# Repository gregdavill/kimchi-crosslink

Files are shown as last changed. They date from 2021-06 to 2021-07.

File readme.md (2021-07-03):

# kimχ micro lid Crosslink-nx

This project is an add-on (lid) expansion board for the [kimχ micro i.MX8M Mini SBC](https://labs.groupgets.com/kimchi-micro).

This board is designed as a general purpose plotform for the Lattice Crosslink-nx FPGA, but it's main purpose is to investigate the options for converting the 4-lane MIPI-DSI signals from the Kimchi to a standard HDMI monitor.

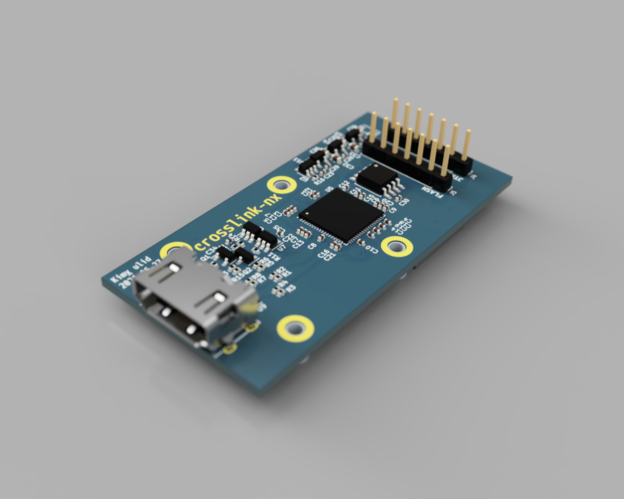
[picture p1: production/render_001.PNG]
Render 001

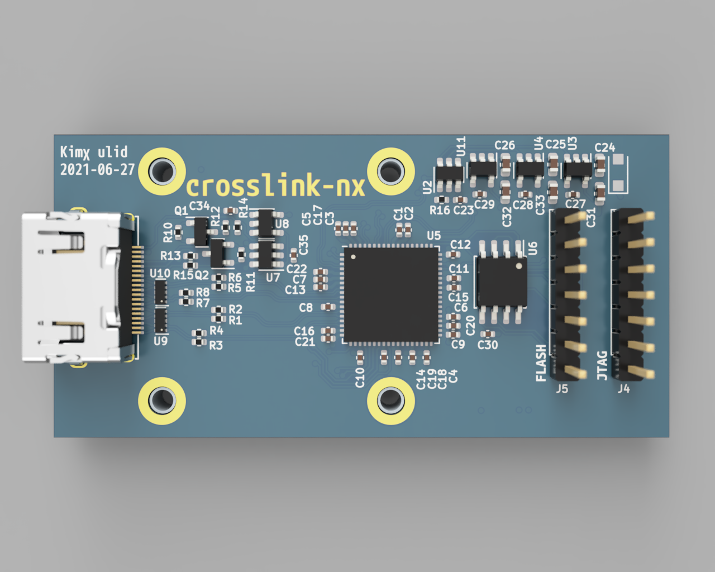
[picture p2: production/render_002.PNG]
Render 002


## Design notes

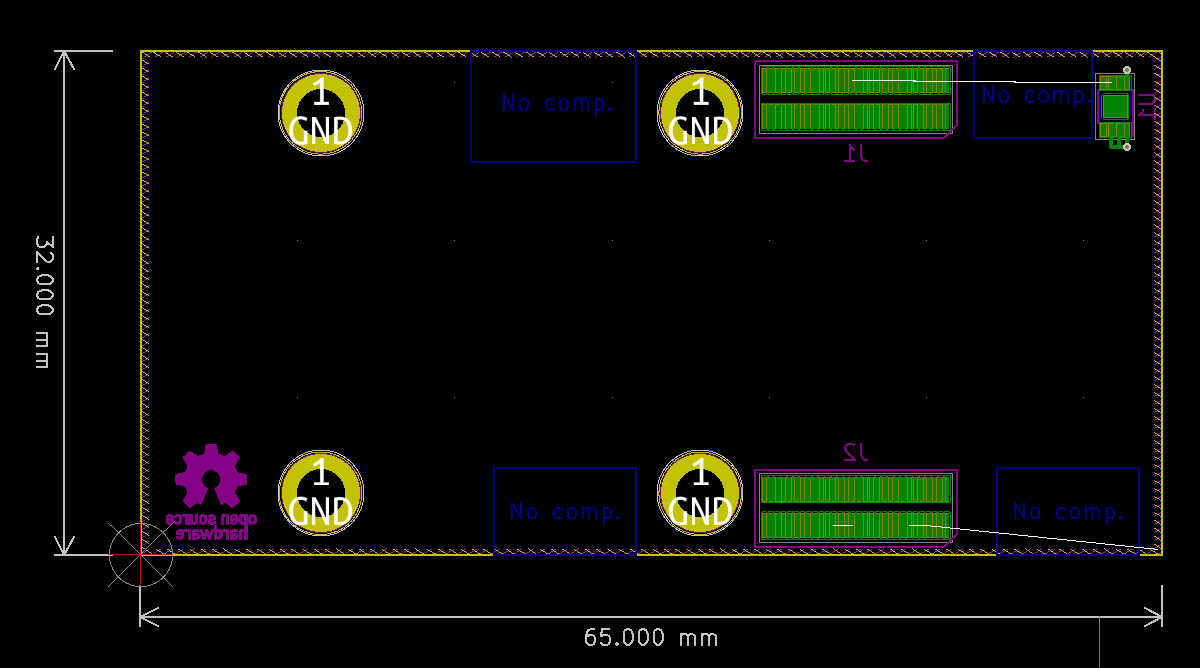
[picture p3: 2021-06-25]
meta/brd.png

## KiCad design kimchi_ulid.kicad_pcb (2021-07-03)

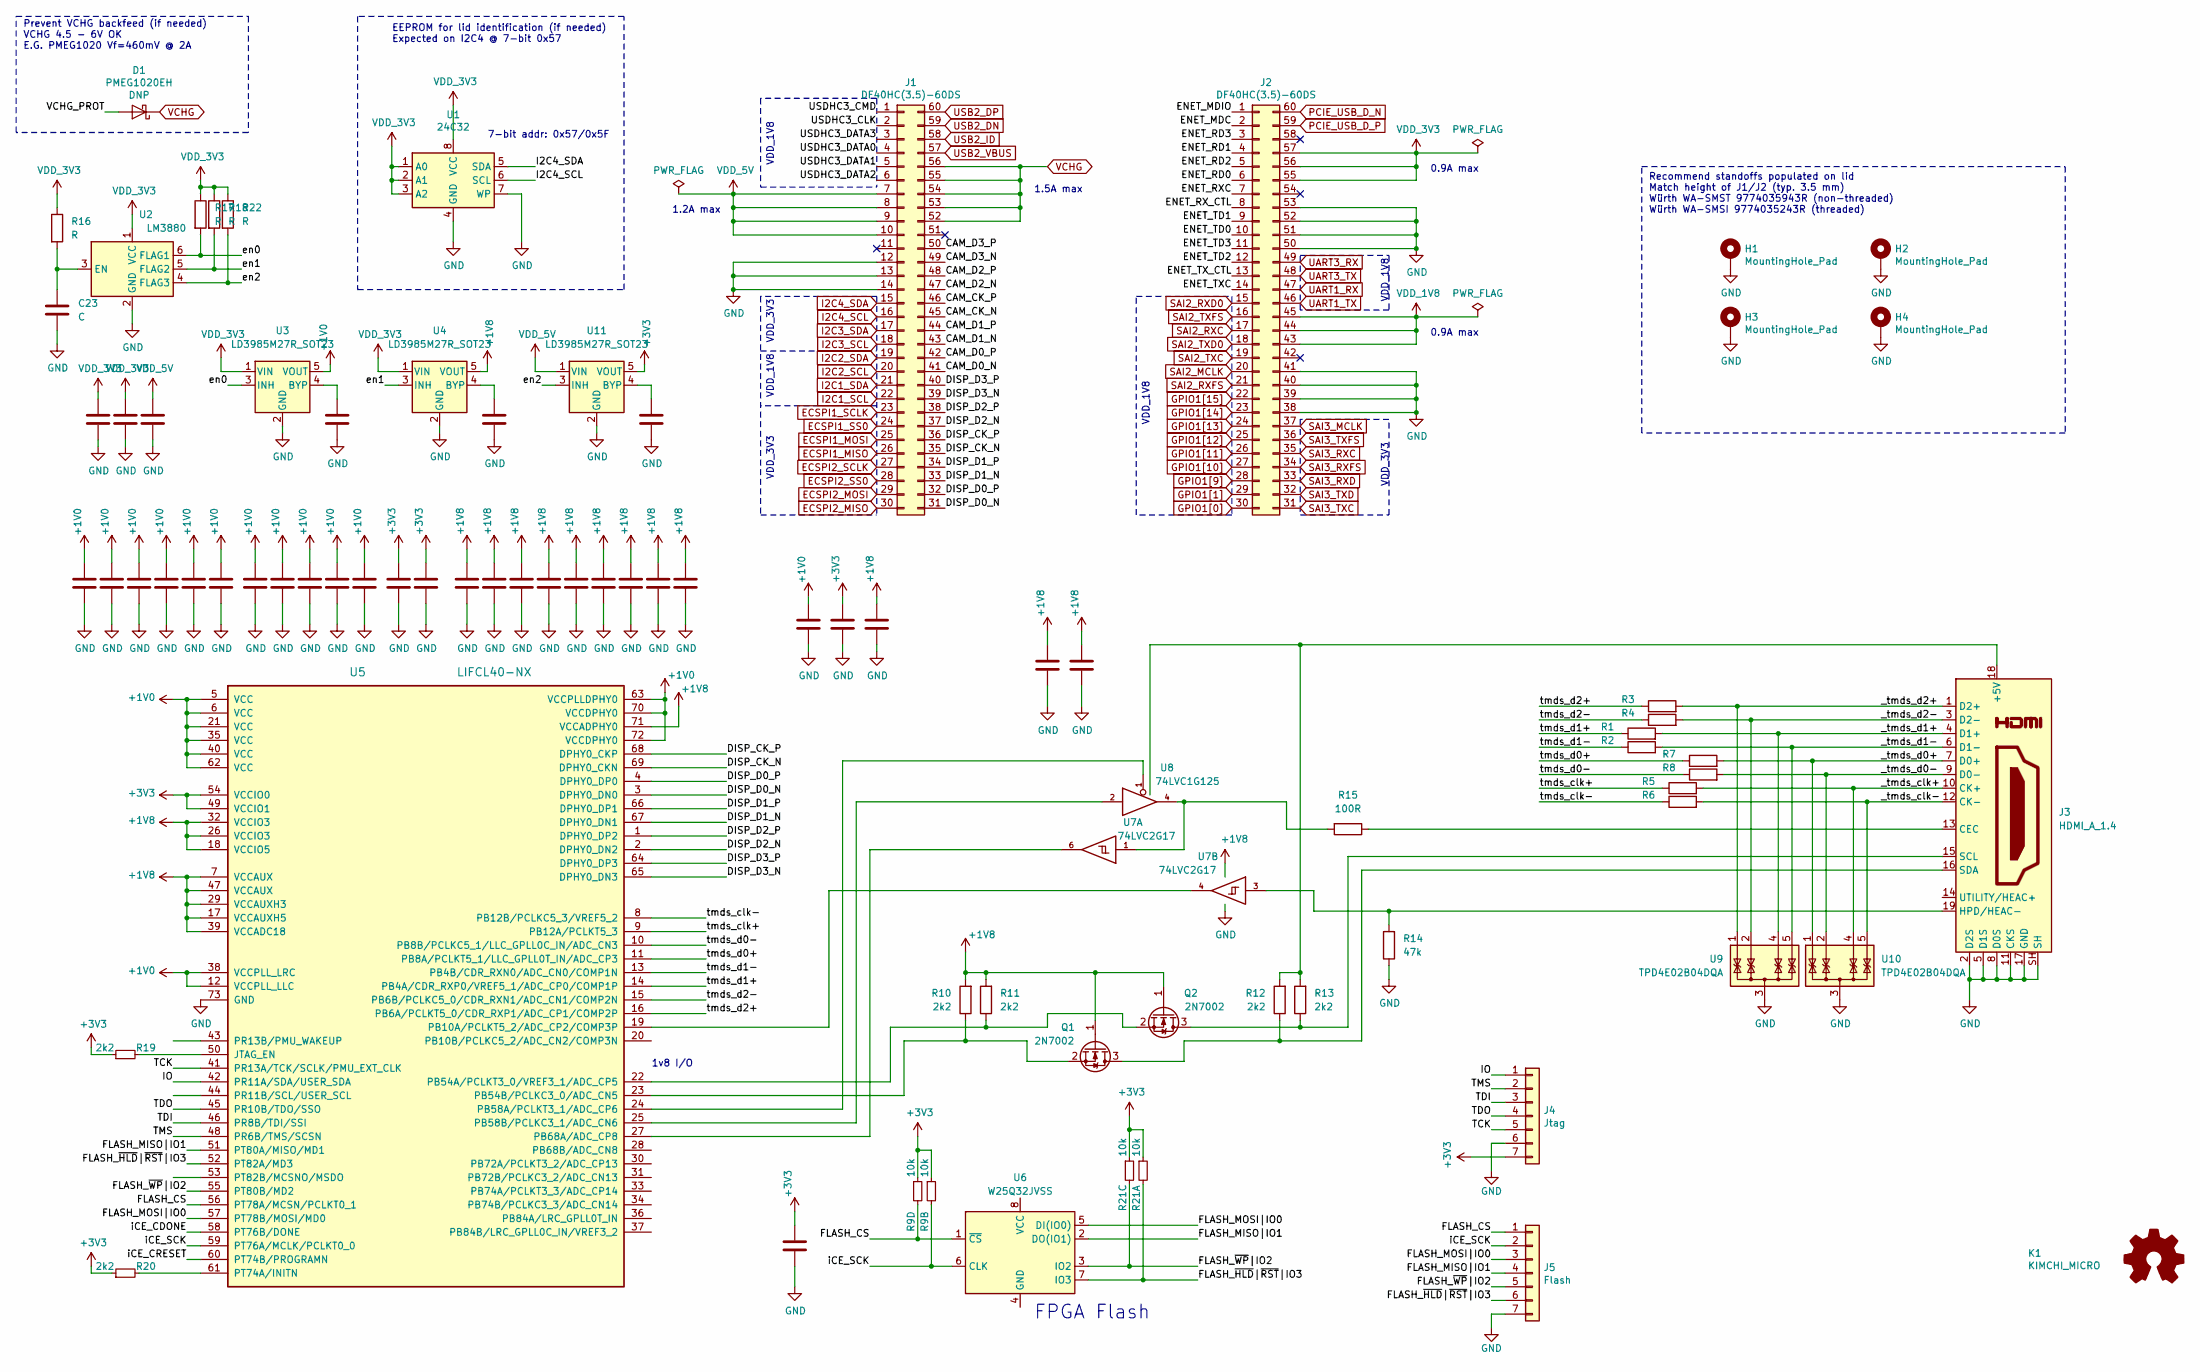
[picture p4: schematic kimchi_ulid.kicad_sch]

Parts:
C1, C2, C3, C4, C5, C6, C7, C8, C9, C10, C11, C12, C13, C14, C15, C16, C17, C18, C19, C20, C21, C22, C30, C34, C35: 0.1uF; C_0402_1005Metric
C23: C; C_0402_1005Metric
C24, C25, C26: 4.7uF; C_0603_1608Metric
C27, C28, C29: 0.01uF; C_0402_1005Metric
C31, C32, C33: 10uF; C_0603_1608Metric
D1: PMEG1020EH; D_SOD-123F
H1, H2, H3, H4: MountingHole_Pad; MountingHole_M2_Standoff; Mfgrpart 9774035943R
J1, J2: DF40HC(3.5)-60DS
J3: HDMI_A_1.4; HDMI-10029449-111RLF
J4: Jtag; PinHeader_1x07_P2.54mm_Vertical
J5: Flash; PinHeader_1x07_P2.54mm_Vertical
K1: KIMCHI_MICRO
LOGO1: Logo_Open_Hardware_Small; OSHW-Logo_5.7x6mm_SilkScreen
Q1, Q2: 2N7002; SOT-23
R1, R2, R3, R4, R5, R6, R7, R8, R16: R; R_0402_1005Metric
R9, R21: 10k; R_Array_Convex_4x0402
R10, R11, R12, R13: 2k2; R_0402_1005Metric
R14: 47k; R_0402_1005Metric
R15: 100R; R_0402_1005Metric
R17, R18, R22: R
R19, R20: 2k2; R_0402
U1: 24C32; DFN-8-1EP_3x2mm_P0.5mm_EP1.36x1.46mm; Part M24C32-FMC6TG
U2: LM3880; SOT-23-6
U3, U4, U11: LD3985M27R_SOT23; SOT-23-5
U5: LIFCL40-NX; QFN-72-1EP_10x10mm_P0.5mm_EP6x6mm
U6: W25Q32JVSS; SOIC-8_5.23x5.23mm_P1.27mm
U7: 74LVC2G17; SOT-23-6
U8: 74LVC1G125; SOT-23-5
U9, U10: TPD4E02B04DQA; USON-10_2.5x1.0mm_P0.5mm

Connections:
+1V0: C1.1, C2.1, C3.1, C4.1, C5.1, C6.1, C7.1, C8.1, C9.1, C10.1, C22.1, C31.1, U3.5 (VOUT), U5.5 (VCC), U5.6 (VCC), U5.12 (VCCPLL_LLC), U5.21 (VCC), U5.35 (VCC), U5.38 (VCCPLL_LRC), U5.40 (VCC), U5.62 (VCC), U5.63 (VCCPLLDPHY0), U5.70 (VCCDPHY0), U5.72 (VCCDPHY0)
+1V8: C13.1, C14.1, C15.1, C16.1, C17.1, C18.1, C19.1, C20.1, C21.1, C33.1, C34.1, C35.1, Q1.1 (G), Q2.1 (G), R10.2, R11.2, U4.5 (VOUT), U5.7 (VCCAUX), U5.17 (VCCAUXH5), U5.18 (VCCIO5), U5.26 (VCCIO3), U5.29 (VCCAUXH3), U5.32 (VCCIO3), U5.39 (VCCADC18), U5.47 (VCCAUX), U5.71 (VCCADPHY0), U7.5 (VCC)
+3V3: C11.1, C12.1, C30.1, C32.1, J4.7, R9.3, R9.7, R20.1, R21.1, R21.5, U5.49 (VCCIO1), U5.54 (VCCIO0), U11.5 (VOUT)
/CAM_CK_N: J1.45
/CAM_CK_P: J1.46
/CAM_D0_N: J1.41
/CAM_D0_P: J1.42
/CAM_D1_N: J1.43
/CAM_D1_P: J1.44
/CAM_D2_N: J1.47
/CAM_D2_P: J1.48
/CAM_D3_N: J1.49
/CAM_D3_P: J1.50
/DISP_CK_N: J1.35, U5.69 (DPHY0_CKN)
/DISP_CK_P: J1.36, U5.68 (DPHY0_CKP)
/DISP_D0_N: J1.31, U5.3 (DPHY0_DN0)
/DISP_D0_P: J1.32, U5.4 (DPHY0_DP0)
/DISP_D1_N: J1.33, U5.67 (DPHY0_DN1)
/DISP_D1_P: J1.34, U5.66 (DPHY0_DP1)
/DISP_D2_N: J1.37, U5.2 (DPHY0_DN2)
/DISP_D2_P: J1.38, U5.1 (DPHY0_DP2)
/DISP_D3_N: J1.39, U5.65 (DPHY0_DN3)
/DISP_D3_P: J1.40, U5.64 (DPHY0_DP3)
/ENET_MDC: J2.2
/ENET_MDIO: J2.1
/ENET_RD0: J2.6
/ENET_RD1: J2.4
/ENET_RD2: J2.5
/ENET_RD3: J2.3
/ENET_RXC: J2.7
/ENET_RX_CTL: J2.8
/ENET_TD0: J2.10
/ENET_TD1: J2.9
/ENET_TD2: J2.12
/ENET_TD3: J2.11
/ENET_TXC: J2.14
/ENET_TX_CTL: J2.13
/FLASH_CS: J5.1, R9.8, U5.56 (PT78A/MCSN/PCLKT0_1), U6.1 (~CS)
/FLASH_MISO|IO1: J5.4, U5.51 (PT80A/MISO/MD1), U6.2 (DO(IO1))
/FLASH_MOSI|IO0: J5.3, U5.57 (PT78B/MOSI/MD0), U6.5 (DI(IO0))
/FLASH_~HLD|~RST|IO3: J5.6, R21.2, U5.52 (PT82A/MD3), U6.7 (IO3)
/FLASH_~WP|IO2: J5.5, R21.6, U5.55 (PT80B/MD2), U6.3 (IO2)
/IO: J4.1, U5.42 (PR11A/SDA/USER_SDA)
/TCK: J4.5, U5.41 (PR13A/TCK/SCLK/PMU_EXT_CLK)
/TDI: J4.3, U5.46 (PR8B/TDI/SSI)
/TDO: J4.4, U5.45 (PR10B/TDO/SSO)
/TMS: J4.2, U5.48 (PR6B/TMS/SCSN)
/USDHC3_CLK: J1.2
/USDHC3_CMD: J1.1
/USDHC3_DATA0: J1.4
/USDHC3_DATA1: J1.5
/USDHC3_DATA2: J1.6
/USDHC3_DATA3: J1.3
/VCHG_PROT: D1.2 (A)
/_tmds_clk+: J3.10 (CK+), R5.2, U10.4 (IO3)
/_tmds_clk-: J3.12 (CK-), R6.2, U10.5 (IO4)
/_tmds_d0+: J3.7 (D0+), R7.2, U10.1 (IO1)
/_tmds_d0-: J3.9 (D0-), R8.2, U10.2 (IO2)
/_tmds_d1+: J3.4 (D1+), R1.2, U9.4 (IO3)
/_tmds_d1-: J3.6 (D1-), R2.2, U9.5 (IO4)
/_tmds_d2+: J3.1 (D2+), R3.2, U9.1 (IO1)
/_tmds_d2-: J3.3 (D2-), R4.2, U9.2 (IO2)
/en0: R17.2, U2.6 (FLAG1), U3.3 (INH)
/en1: R18.2, U2.5 (FLAG2), U4.3 (INH)
/en2: R22.2, U2.4 (FLAG3), U11.3 (INH)
/iCE_CDONE: U5.58 (PT76B/DONE)
/iCE_CRESET: U5.60 (PT74B/PROGRAMN)
/iCE_SCK: J5.2, R9.4, U5.59 (PT76A/MCLK/PCLKT0_0), U6.6 (CLK)
/tmds_clk+: R5.1, U5.9 (PB12A/PCLKT5_3)
/tmds_clk-: R6.1, U5.8 (PB12B/PCLKC5_3/VREF5_2)
/tmds_d0+: R7.1, U5.11 (PB8A/PCLKT5_1/LLC_GPLL0T_IN/ADC_CP3)
/tmds_d0-: R8.1, U5.10 (PB8B/PCLKC5_1/LLC_GPLL0C_IN/ADC_CN3)
/tmds_d1+: R1.1, U5.14 (PB4A/CDR_RXP0/VREF5_1/ADC_CP0/COMP1P)
/tmds_d1-: R2.1, U5.13 (PB4B/CDR_RXN0/ADC_CN0/COMP1N)
/tmds_d2+: R3.1, U5.16 (PB6A/PCLKT5_0/CDR_RXP1/ADC_CP1/COMP2P)
/tmds_d2-: R4.1, U5.15 (PB6B/PCLKC5_0/CDR_RXN1/ADC_CN1/COMP2N)
ECSPI1_MISO: J1.26
ECSPI1_MOSI: J1.25
ECSPI1_SCLK: J1.23
ECSPI1_SS0: J1.24
ECSPI2_MISO: J1.30
ECSPI2_MOSI: J1.29
ECSPI2_SCLK: J1.27
ECSPI2_SS0: J1.28
GND: C1.2, C2.2, C3.2, C4.2, C5.2, C6.2, C7.2, C8.2, C9.2, C10.2, C11.2, C12.2, C13.2, C14.2, C15.2, C16.2, C17.2, C18.2, C19.2, C20.2, C21.2, C22.2, C23.2, C24.2, C25.2, C26.2, C27.2, C28.2, C29.2, C30.2, C31.2, C32.2, C33.2, C34.2, C35.2, H1.1, H2.1, H3.1, H4.1, J1.12, J1.13, J1.14, J2.38, J2.39, J2.40, J2.41, J2.50, J2.51, J2.52, J2.53, J3.2 (D2S), J3.5 (D1S), J3.8 (D0S), J3.11 (CKS), J3.17 (GND), J3.SH, J4.6, J5.7, R14.1, U1.4 (GND), U1.7 (WP), U2.2 (GND), U3.2 (GND), U4.2 (GND), U5.73 (GND), U7.2 (GND), U8.3 (GND), U9.3 (G), U9.8 (G), U10.3 (G), U10.8 (G), U11.2 (GND)
GPIO1[0]: J2.30
GPIO1[1]: J2.29
GPIO1[9]: J2.28
GPIO1[10]: J2.27
GPIO1[11]: J2.26
GPIO1[12]: J2.25
GPIO1[13]: J2.24
GPIO1[14]: J2.23
GPIO1[15]: J2.22
I2C1_SCL: J1.22
I2C1_SDA: J1.21
I2C2_SCL: J1.20
I2C2_SDA: J1.19
I2C3_SCL: J1.18
I2C3_SDA: J1.17
I2C4_SCL: J1.16, U1.6 (SCL)
I2C4_SDA: J1.15, U1.5 (SDA)
unnamed: C23.1, R16.2, U2.3 (EN)
unnamed: C27.1, U3.4 (BYP)
unnamed: C28.1, U4.4 (BYP)
unnamed: C29.1, U11.4 (BYP)
unnamed: J3.13 (CEC), R15.1
unnamed: J3.15 (SCL), Q2.3 (D), R13.1
unnamed: J3.16 (SDA), Q1.3 (D), R12.1
unnamed: J3.19 (HPD/HEAC-), R14.2, U7.3
unnamed: Q1.2 (S), R10.1, U5.23 (PB54B/PCLKC3_0/ADC_CN5)
unnamed: Q2.2 (S), R11.1, U5.22 (PB54A/PCLKT3_0/VREF3_1/ADC_CP5)
unnamed: R15.2, U7.1, U8.4
unnamed: R19.2, U5.50 (JTAG_EN)
unnamed: R20.2, U5.61 (PT74A/INITN)
unnamed: U5.19 (PB10A/PCLKT5_2/ADC_CP2/COMP3P), U7.4
unnamed: U5.24 (PB58A/PCLKT3_1/ADC_CP6), U8.1
unnamed: U5.25 (PB58B/PCLKC3_1/ADC_CN6), U8.2
unnamed: U5.27 (PB68A/ADC_CP8), U7.6
PCIE_USB_D_N: J2.60
PCIE_USB_D_P: J2.59
SAI2_MCLK: J2.20
SAI2_RXC: J2.17
SAI2_RXD0: J2.15
SAI2_RXFS: J2.21
SAI2_TXC: J2.19
SAI2_TXD0: J2.18
SAI2_TXFS: J2.16
SAI3_MCLK: J2.37
SAI3_RXC: J2.35
SAI3_RXD: J2.33
SAI3_RXFS: J2.34
SAI3_TXC: J2.31
SAI3_TXD: J2.32
SAI3_TXFS: J2.36
UART1_RX: J2.47
UART1_TX: J2.46
UART3_RX: J2.49
UART3_TX: J2.48
USB2_DN: J1.59
USB2_DP: J1.60
USB2_ID: J1.58
USB2_VBUS: J1.57
VCHG: D1.1 (K), J1.52, J1.53, J1.54, J1.55, J1.56
VDD: J3.18 (+5V), R12.2, R13.2, U8.5 (VDD)
VDD_1V8: J2.43, J2.44, J2.45
VDD_3V3: C24.1, C25.1, J2.55, J2.56, J2.57, R16.1, R17.1, R18.1, R22.1, U1.1 (A0), U1.2 (A1), U1.3 (A2), U1.8 (VCC), U2.1 (VCC), U3.1 (VIN), U4.1 (VIN)
VDD_5V: C26.1, J1.7, J1.8, J1.9, J1.10, U11.1 (VIN)

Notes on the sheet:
Prevent VCHG backfeed (if needed) VCHG 4.5 - 6V OK E.G. PMEG1020 Vf=460mV @ 2A
EEPROM for lid identification (if needed) Expected on I2C4 @ 7-bit 0x57
7-bit addr: 0x57/0x5F
1v8 I/O
1.2A max
VDD_1V8
VDD_3V3
1.5A max
FPGA Flash
0.9A max
Recommend standoffs populated on lid Match height of J1/J2 (typ. 3.5 mm) Würth WA-SMST 9774035943R (non-threaded) Würth WA-SMSI 9774035243R (threaded)

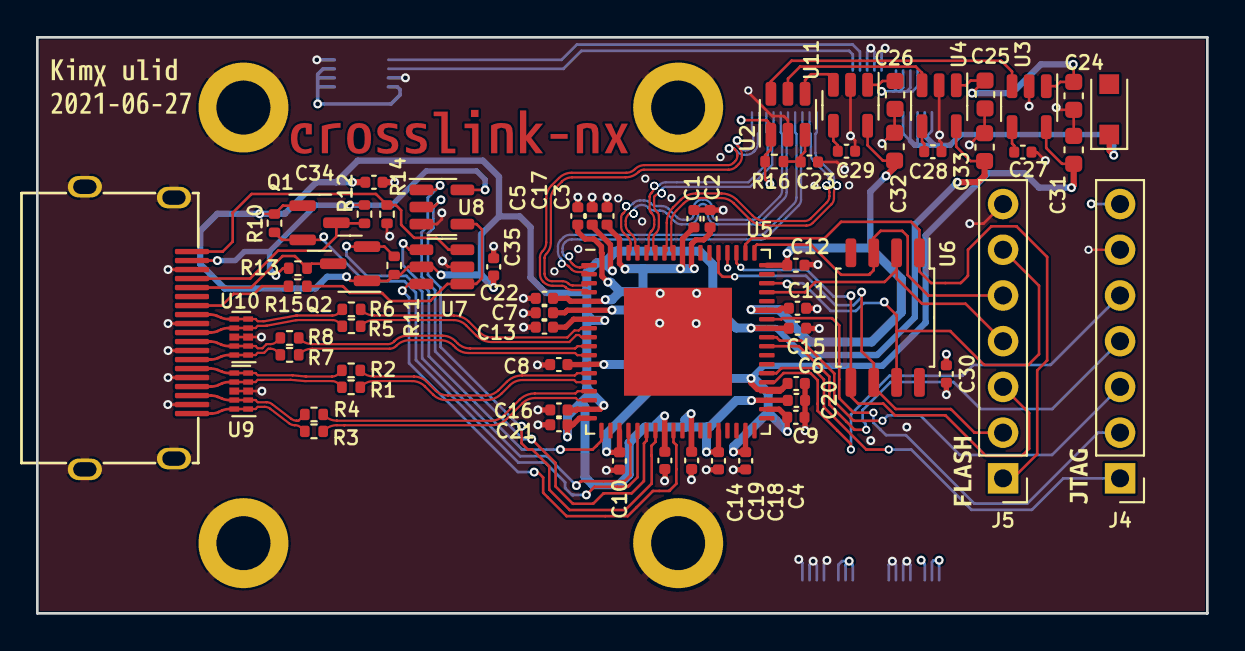
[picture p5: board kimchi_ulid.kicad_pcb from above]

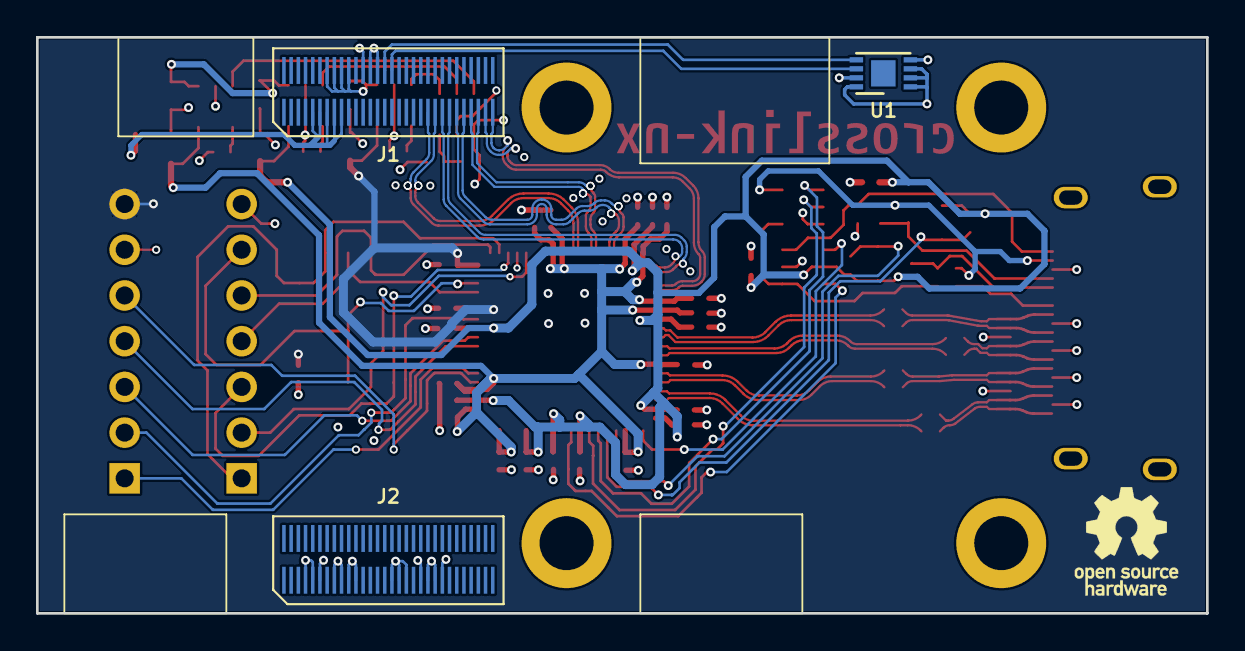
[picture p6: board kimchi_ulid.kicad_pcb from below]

Board: 4 copper layers, 65.0 x 32.0 mm, 80 parts (9 on the bottom side), 66 nets.

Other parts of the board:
svg2mod, svg2mod#2, svg2mod#3, svg2mod#4, svg2mod#5: G***; svg2mod

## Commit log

2021-06-27 Initial work on design
    - Update symbols to KiCad v6
    - Start inital placement and routing of design
    [kimchi_ulid.kicad_pcb, kimchi_ulid.kicad_sch]
2021-06-27 Update routing
    [kimchi_ulid.kicad_pcb, kimchi_ulid.kicad_sch]
2021-07-03 Update
    - Complete inital routing
    - Render a board view and update readme
    [kimchi_ulid.kicad_pcb, kimchi_ulid.kicad_sch]
